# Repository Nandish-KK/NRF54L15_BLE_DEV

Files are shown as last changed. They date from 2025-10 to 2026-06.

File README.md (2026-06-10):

Project Banner

## Overview
This repository contains design files, libraries, and documentation for the NRF BLE transceiver project.
It is **not** an official NRF development board; it is a project I designed as an exercise while learning Altium Designer.

Project Render
(Renderd with [Blender](https://www.blender.org/) using [*pcb2blender*](https://github.com/30350n/pcb2blender) plugin for KiCAD)

## Things to play around with

- 6-axis IMU (BMI270)
- WS2812 Addressable RGB LED
- Coin cell operation
- Antenna switch for External antenna

## Folder Structure

```text
3D/				  # Contains STEP and Blender files
Altium/           # Altium project files and libraries
Datasheet/        # Datasheets and reference documents
Gerbers/          # Gerbers with PCB constraints optimized for JLCPCB
Pictures/         # Contains Render and Readme pictures
Reference/        # Additional reference layouts and guides
```

## Getting Started

1. Clone the repository:
	```bash
	git clone https://github.com/Nandish-KK/NRF54L15_BLE_DEV
	```
2. Open the Altium project file in `Altium/Nordic_BLE/Nordic_BLE.PrjPcb`.
3. Optionally you can import the Altium project in latest Kicad releases.

## Stackup

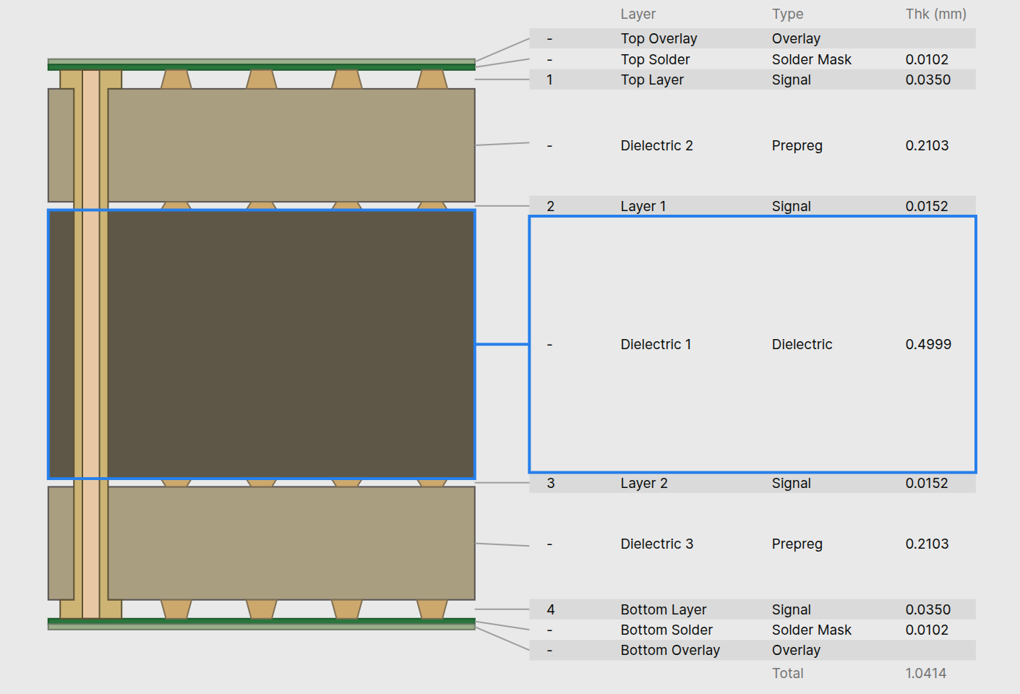
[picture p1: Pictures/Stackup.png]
Stackup


JLC04101H-7628

This is a 4-layer stackup with both of the Inner layers being solid ground planes.

## Project Preview

### Schematic
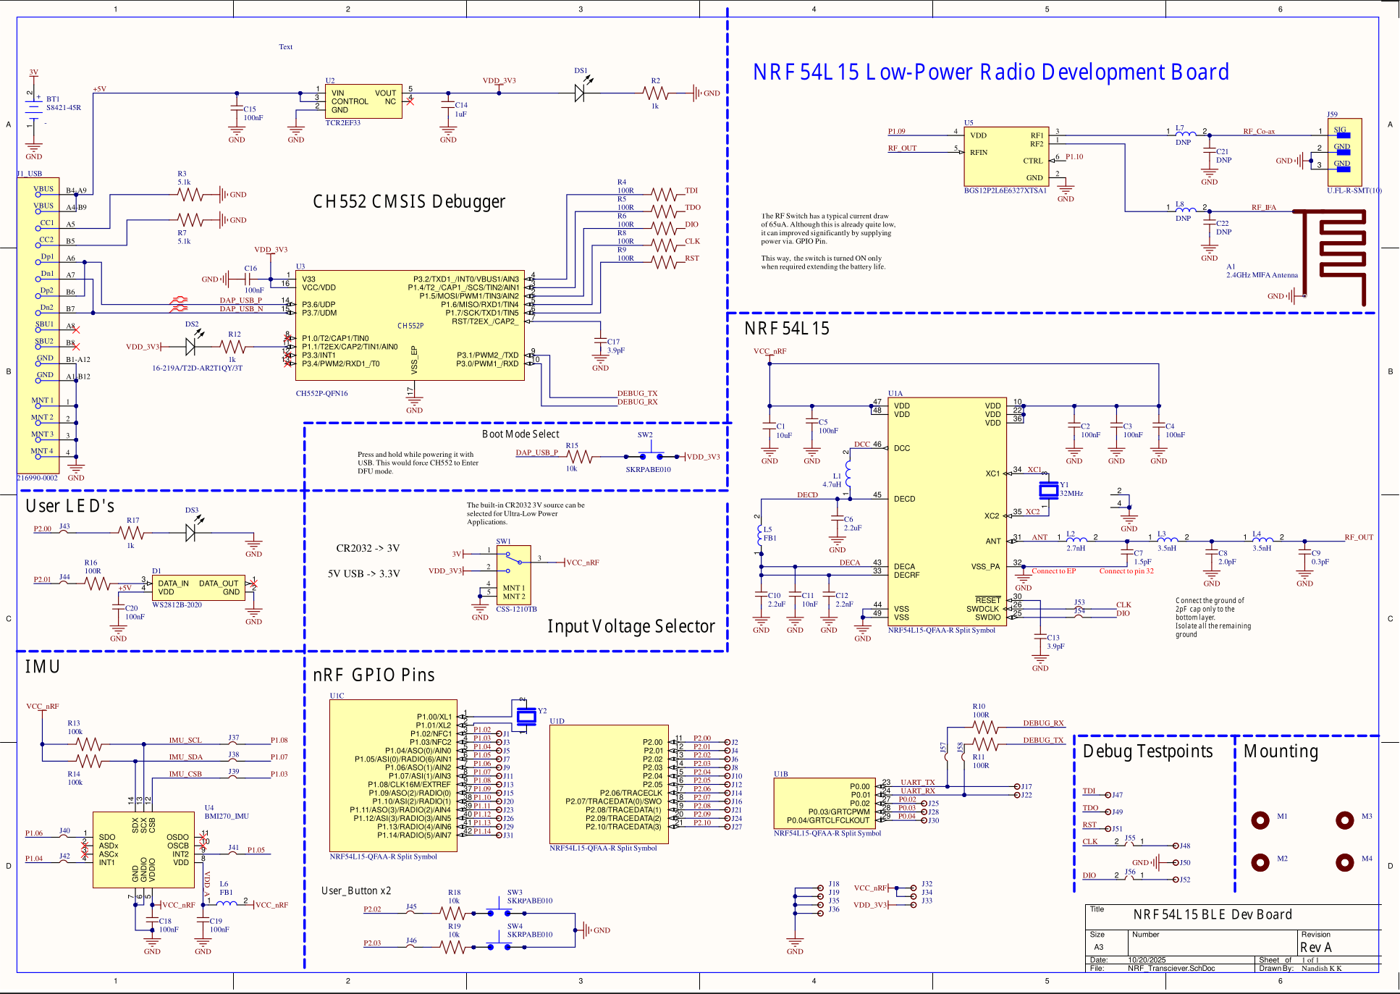
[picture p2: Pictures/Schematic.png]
Schematic Preview


### Top 3D View
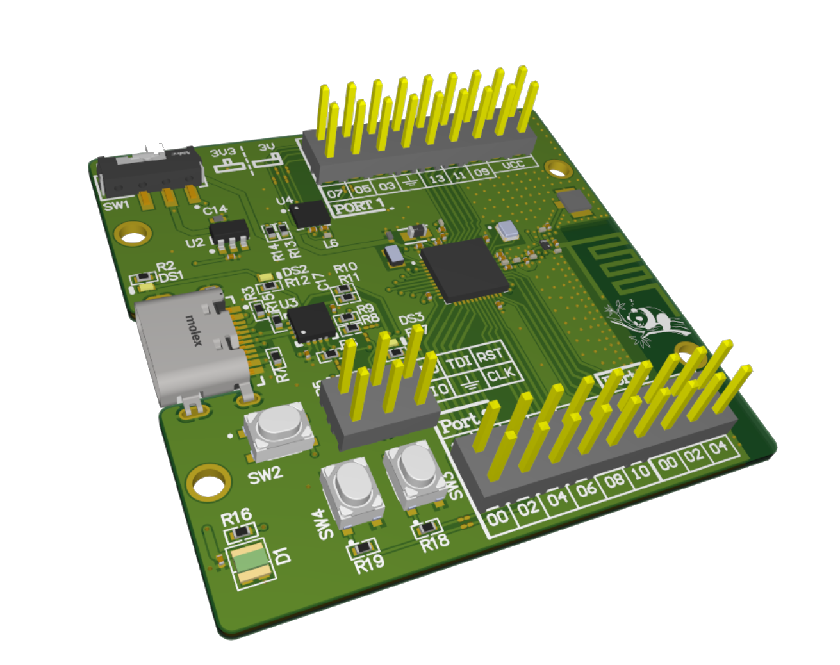
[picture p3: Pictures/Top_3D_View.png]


### Top Layer
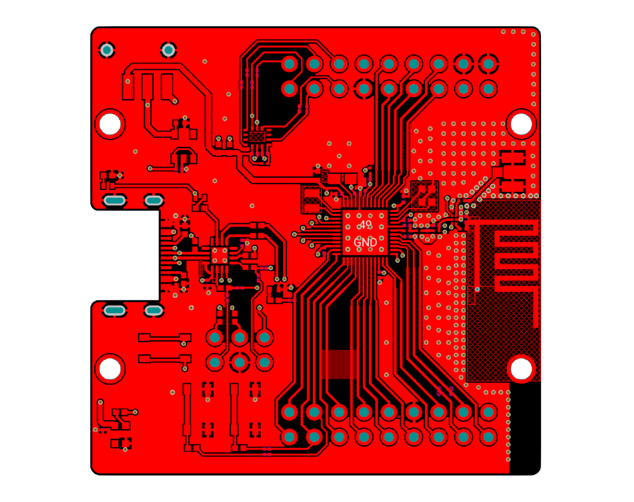
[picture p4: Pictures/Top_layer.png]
Layer_Top


### Bottom Layer
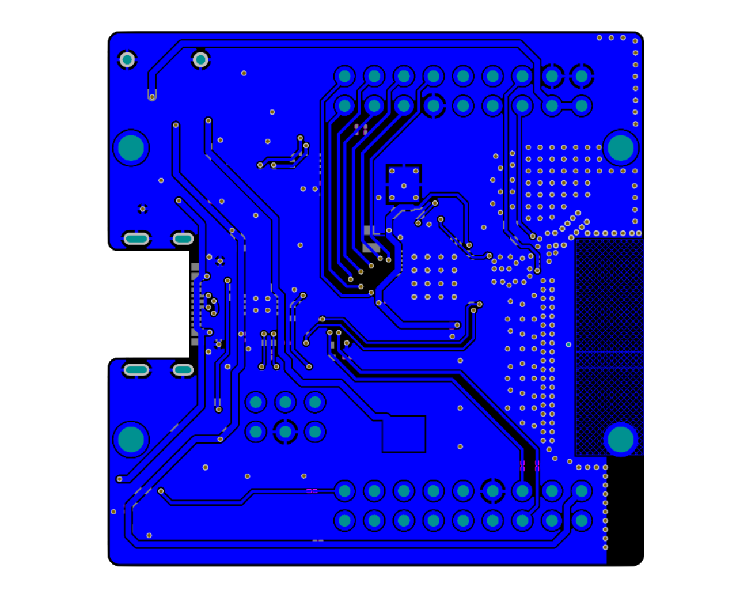
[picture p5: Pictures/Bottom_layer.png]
Layer_Bottom


### Bottom 3D View
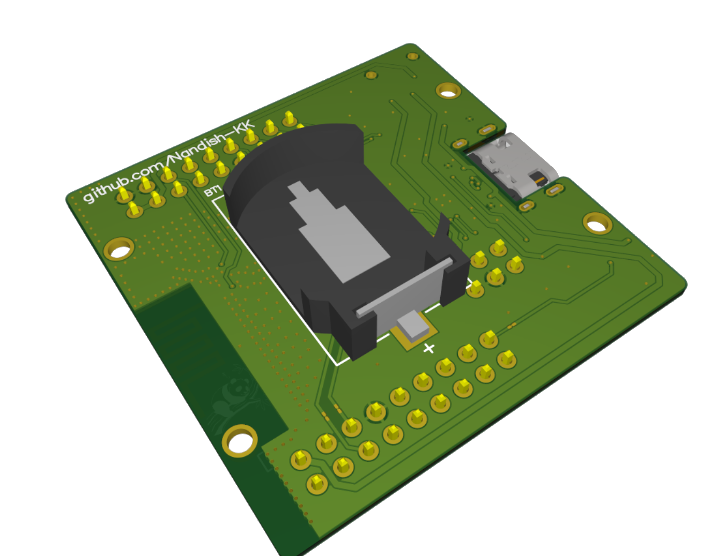
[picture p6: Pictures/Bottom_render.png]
Layer_Bottom


## Development bugs and fixes
The nrf54 controller comes with `AP_PROTECT` enabled by default. The debuggeres are unable to access the cpu and user flash memory for flashing. In order to unlock the `AP_PROTECT` and get access to the device, the nrf documentation recommends "mass erase". This process will clear the protection registers and allow for flashing.

If your using pyocd inside the nrf-connect terminal with west. During flash it will automatically detect the protection state and will try to erase before flashing. If that doesn't work, try external resets.
```bash
#from the project directory
$ west flash -d build_1/ -r pyocd

# --- OUTPUT ---
-- west flash: rebuilding
[0/5] Performing build step for 'hello_world'
ninja: no work to do.
[4/5] cd /home/user/path/to/project/dir/hello_world/build_1/_sysbuild && /home/user/ncs/toolchains/b2ecd2435d/usr/local/bin/cmake -E true
-- west flash: using runner pyocd
-- runners.pyocd: Flashing file: /media/renri/Hard_disk_Part1/NRF_playground/hello_world/build_1/merged.hex
0000496 W NRF54L15 APPROTECT enabled: will try to unlock via mass erase [target_nRF54L]
0001425 I Loading /home/user/path/to/project/dir/hello_world/build_1/merged.hex [load_cmd]
[==================================================] 100%
0005148 I Erased 36864 bytes (9 sectors), programmed 36864 bytes (9 pages), skipped 0 bytes (0 pages) at 9.75 kB/s [loader]
```

If the protection is enabled, the openenocd 'targets' command will report the main cpu status as unknown as shown below.

```
					 --- Locked State ---
> targets
    TargetName         Type       Endian TapName            State       
--  ------------------ ---------- ------ ------------------ ------------
 0* nrf54l.cpu         cortex_m   little nrf54l.cpu         unknown
 1  nrf54l.aux         mem_ap     little nrf54l.cpu         running

					--- Unlocked State ---
 > targets
    TargetName         Type       Endian TapName            State       
--  ------------------ ---------- ------ ------------------ ------------
 0* nrf54l.cpu         cortex_m   little nrf54l.cpu         running
 1  nrf54l.aux         mem_ap     little nrf54l.cpu         running
````

You can use the following pyocd commands to erase the chip. Although you can connect via openocd, there doesn't seem to be a relibale way to erase the chip with `AP_PROTECT` enabled.
Use the pyocd provided along with the nrf connect or install the latest version of pyocd if you prefere to use it externally. 

```bash
$ pyocd erase --mass --target nrf54l

# --- OUTPUT ---
0000395 W NRF54L15 is not in a secure state [target_nRF54L]
0000608 I Mass erasing device... [eraser]
0001324 I Mass erase complete [eraser]

```
If pyocd command fails to erase/flash with cmsis debugger, try power cycling.

[Working with the nRF52 Series' improved APPROTECT](https://devzone.nordicsemi.com/nordic/nordic-blog/b/blog/posts/working-with-the-nrf52-series-improved-approtect). 

Currently, I don't have J-link at hand. This meant I had to do quite a bit of detective work to come up with a solution. I found the solution in the seedstudio forum discussion on Xiao-nrf54l15. The discussion provides quite a bit of insight on the issues that you might face.
[Xiao-nrf54l15 Memory transfer fault](https://forum.seeedstudio.com/t/xiao-nrf54l15-an-error-occurred-memory-transfer-fault-0x00ffc31c-0x00ffc31f/293792/26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)
[Control access port protection documentation]

## Design Notes

* Hold the Boot button for uploading the CMSIS-DAP firmware for CH552 (first time only)
* Use the toggle switch to select the USB or Coin-cell operation
* The Antenna switch is powered with the GPIO _P1.09 and is controlled by GPIO P1.10; configure GPIOs for proper RF operation.
* Every GPIO used onboard has a bridger solder link. If any project requires these GPIOs externally, simply cut the closed solder bridge trace.

## On-Board Debugger

The Board design utilizes a CH552P microcontroller with a CMSIS-DAP firmware as a built-in debugger for NRF microcontroller. The CH552P is opted mainly due to its low cost and smaller footprint.
If you are designing your own board and would like to have a micro that is available at sites like digikey, mouser etc, then consider the SAMD11 series from microchip. These are fairly optimized for cost and size.

```
This project uses the Debugger implementation from wagiminator's CH552-DAPLink project.
Check out his project at: 

> github.com/wagiminator/CH552-DAPLink
> oshwlab.com/wagiminator/ch552g-daplink

```

## License
This work is licensed under CC BY-SA 4.0.
(https://creativecommons.org/licenses/by-sa/4.0/)

License


---

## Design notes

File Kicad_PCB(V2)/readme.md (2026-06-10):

#Rev 2 changes
- swapped RGB led gpio 
- Increased board dimension to account for better T-line design, testing and implement a pi matching network.

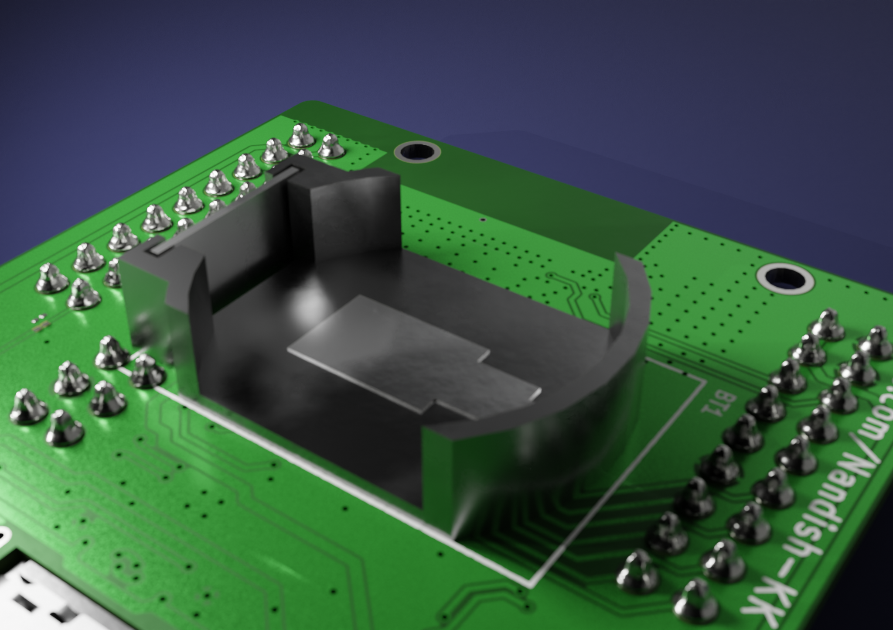
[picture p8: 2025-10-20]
Pictures/Coin_Cell_holder.png

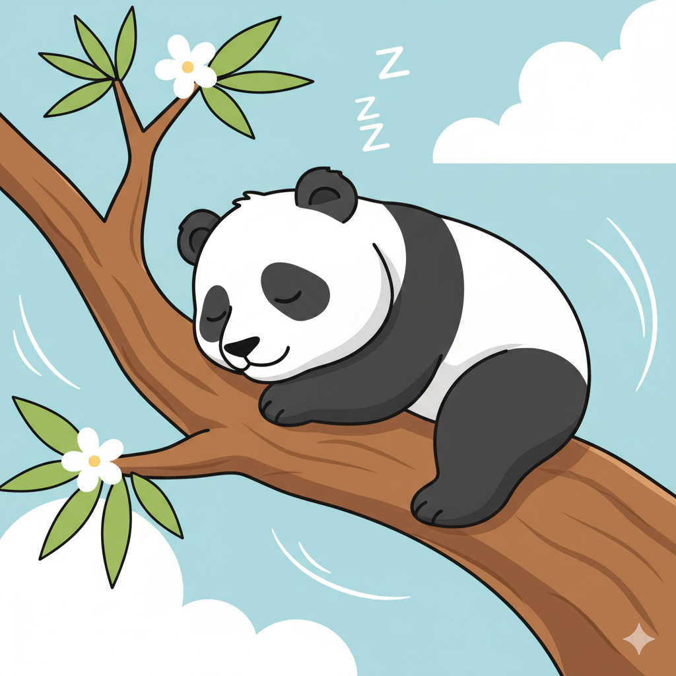
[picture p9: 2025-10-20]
Pictures/Gemini_Generated_Image_Prompt_create a vector like image of a cute panda sleeping on a branch.png

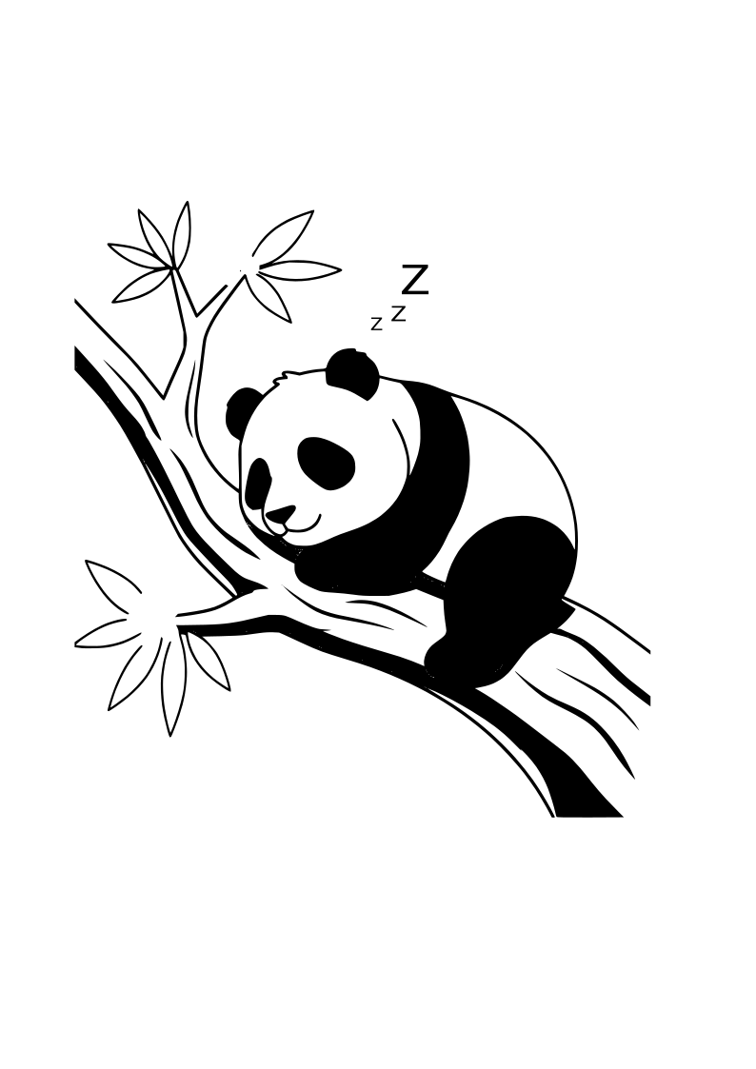
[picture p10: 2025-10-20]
Altium/Nordic_BLE/Sleeping_panda.png

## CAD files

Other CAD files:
3D/IMU_Demo.blend

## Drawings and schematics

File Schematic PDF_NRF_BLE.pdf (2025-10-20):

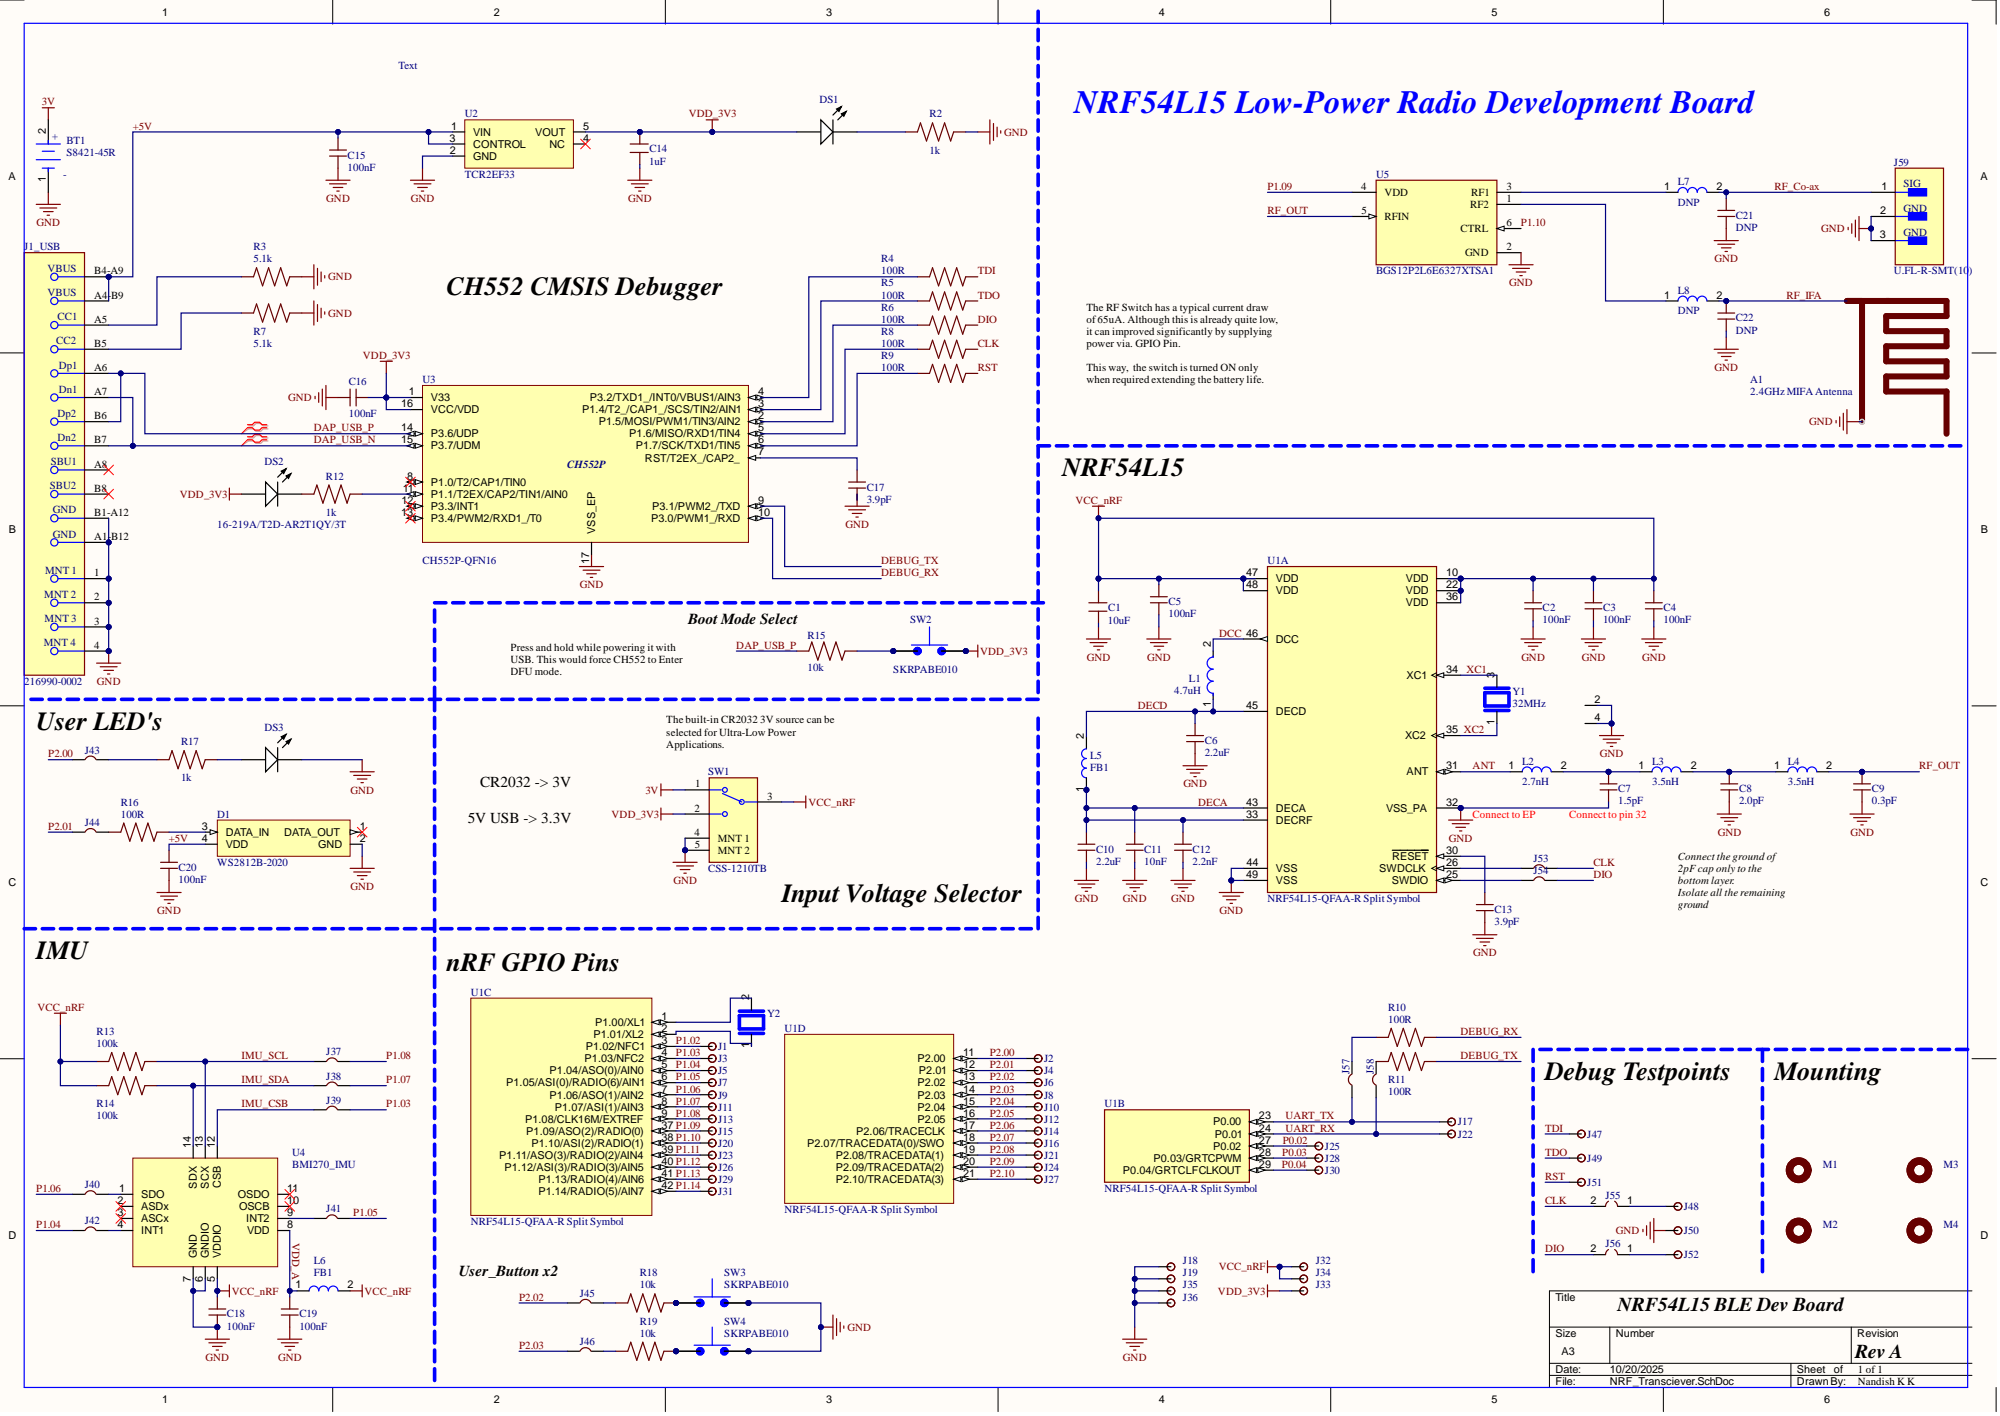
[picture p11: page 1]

NRF54L15 Low-Power Radio Development Board

The RF Switch has a typical current draw
of 65uA. Although this is already quite low,
it can improved significantly by supplying
power via. GPIO Pin.

This way, the switch is turned ON only
when required extending the battery life.

Press and hold while powering it with
USB. This would force CH552 to Enter
DFU mode.

The built-in CR2032 3V source can be
selected for Ultra-Low Power
Applications.

Connect the ground of
2pF cap only to the
bottom layer.
Isolate all the remaining
ground

Size A3 | Number | Revision

Date: 10/20/2025 | Sheet of
File: NRF_Transciever.SchDoc | Drawn By: Nandish K K

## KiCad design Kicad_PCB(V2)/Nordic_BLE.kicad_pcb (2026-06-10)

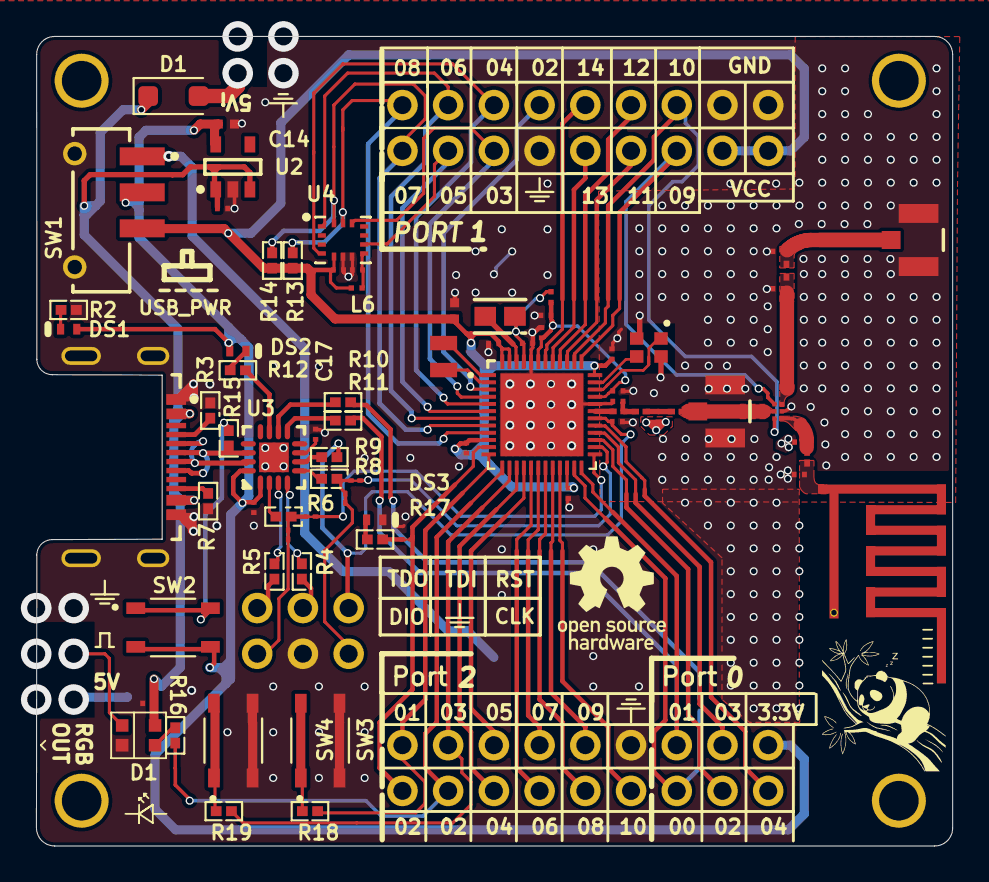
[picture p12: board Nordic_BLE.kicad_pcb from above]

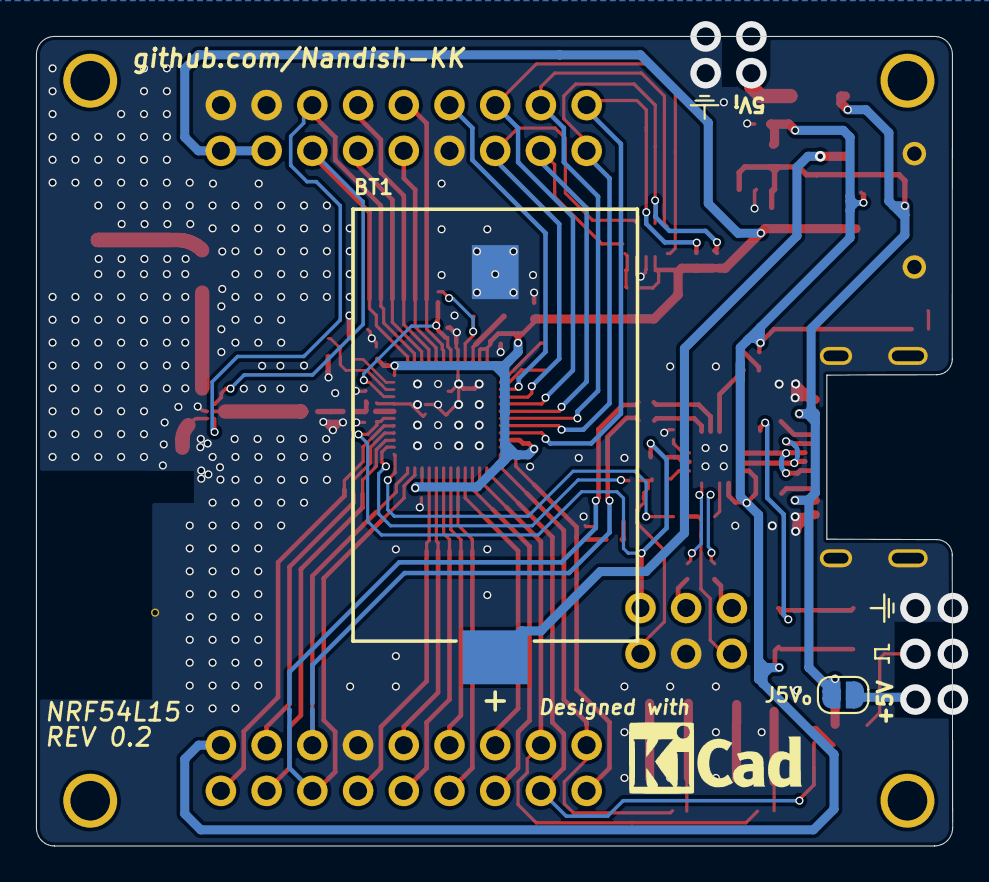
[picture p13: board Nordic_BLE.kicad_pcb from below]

Board: 4 copper layers, 50.9 x 45.0 mm, 124 parts (4 on the bottom side), 82 nets.

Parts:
A1: 2.4GHz MIFA Antenna; 2.4GHZ MIFA
BT1: S8421-45R; FP-S8421-45R-MFG
C1: 10uF; 0402_SMD_CAPACITOR
C2, C3, C4, C5, C15, C16, C18, C19, C20: 100nF; 0201 SMD CAPACITOR
C6, C10: 2.2uF; 0201 SMD CAPACITOR
C7: 1.5pF; 0201 SMD CAPACITOR
C8: 2.0pF; 0201 SMD CAPACITOR
C11: 10nF; 0201 SMD CAPACITOR
C12: 2.2nF; 0201 SMD CAPACITOR
C13, C17: 3.9pF; 0201 SMD CAPACITOR
C14: 1uF; 0402_SMD_CAPACITOR
C21, C21#2, C22, C22#2: DNP; 0201 SMD Capacitor
D1: D_SOD-123F
D1#2: WS2812B-2020
DS1, DS2, DS3: 16-219A/T2D-AR2T1QY/3T; EVRL-0402-2_V
J1, J2, J3, J4, J5, J6, J7, J8, J9, J10, J11, J12, J13, J14, J15, J16, J17, J18, J19, J20, J21, J22, J23, J24, J25, J26, J27, J28, J29, J30, J31, J32, J33, J34, J35, J36, J47, J48, J49, J50, J51, J52: Single_Header_2.54mm; SINGLE_HEADER_2.54MM
J1_USB: 216990-0002; FP-216990-0002-MFG
J5V_{o}: SolderJumper-2_P1.3mm_Open_RoundedPad1.0x1.5mm
J43, J53, J54, J57, J58: Shorted_Solder_Bridge; SHORTED_SOLDER_BRIDGE
J55, J56: Open_Solder_Bridge; OPEN_SOLDER_BRIDGE
J59, J59#2: U.FL-R-SMT(10); FP-U_FL-R-SMT_10-MFG
L1: 4.7uH; FP-MLZ1608-IPC_A
L2: 2.7nH; 0201_SMD_INDUCTOR
L3, L4: 3.5nH; 0201_SMD_INDUCTOR
L5, L6: FB1; 0201_SMD_INDUCTOR
L7, L8: DNP; 0201_SMD_INDUCTOR
M1, M2, M3, M4: M2_Mounting_Hole; M2 MOUNTING HOLE
R2, R12, R17: 1k; RES_0402_GENERIC
R3, R7: 5.1k; RES_0402_GENERIC
R4, R5, R6, R8, R9, R10, R11, R16: 100R; RES_0402_GENERIC
R13, R14: 100k; RES_0402_GENERIC
R15, R18, R19: 10k; RES_0402_GENERIC
SW1: CSS-1210TB; FP-CSS-1210TB-MFG
SW2, SW3, SW4: SKRPABE010; SW_SKRPABE010
U1: NRF54L15-QFAA-R Split Symbol; NRF54L15_LQFN_48
U2: TCR2EF33; TCR2EF33-SOT-23-5
U3: CH552P-QFN16; CH552-QFN16_3X3
U4: BMI270_IMU; BMI_270_PQFN50P300X250X70-14L
U5: BGS12P2L6E6327XTSA1; FP-PG-TSLP-6-MFG
Y1: 32MHz; OSC_XRCGB32M000F2P01R0
Y2: CM8V-T1A-32.768KHZ-9PF-20PPM-TA-QC; XTAL_CM8V-T1A-32.768KHZ-9PF-20PPM-TA-QC

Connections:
3V: BT1.2, SW1.1
+5V: C15.2, C20.2, D1.1, D1#2.4, J1_USB.A4-B9, J1_USB.B4-A9, J5V_{o}.2, U2.1, U2.3
ANT: L2.1, U1.31
CLK: J53.2, J55.2, R8.2
DAP_USB_N: J1_USB.A7, J1_USB.B7, U3.15
DAP_USB_P: J1_USB.A6, J1_USB.B6, R15.1, U3.14
DCC: L1.2, U1.46
DEBUG_RX: R10.1, U3.10
DEBUG_TX: R11.2, U3.9
DECA: C10.2, C11.2, C12.2, L5.1, U1.33, U1.43
DECD: C6.2, L1.1, L5.2, U1.45
DIO: J54.2, J56.2, R6.2
GND: A1.2, BT1.1, C1.1, C2.1, C3.1, C4.1, C5.1, C6.1, C7.1, C8.1, C10.1, C11.1, C12.1, C13.1, C14.1, C15.1, C16.1, C17.1, C18.1, C19.1, C20.1, C21.1, C21#2.1, C22.1, C22#2.1, D1#2.2, DS3.2, J1_USB.1, J1_USB.2, J1_USB.3, J1_USB.4, J1_USB.A1-B12, J1_USB.B1-A12, J18.1, J19.1, J35.1, J36.1, J50.1, J59.2, J59.3, J59#2.2, J59#2.3, R2.1, R3.1, R7.1, SW1.4, SW1.5, SW3.3, SW3.4, SW4.3, SW4.4, U1.32, U1.44, U1.49, U2.2, U3.17, U4.6, U4.7, U5.2, Y1.2, Y1.4
NetC7_2: C7.2, L2.2, L3.1
NetC8_2: C8.2, L3.2, L4.1
NetC17_2: C17.2, U3.7
NetD1_3: D1#2.3, R16.2
NetDS1_2: DS1.2, R2.2
NetDS2_2: DS2.2, R12.2
NetDS3_1: DS3.1, R17.1
NetJ1_USB_A5: J1_USB.A5, R3.2
NetJ1_USB_B5: J1_USB.B5, R7.2
NetJ43_2: J43.2, R17.2
NetJ48_1: J48.1, J55.1
NetJ52_1: J52.1, J56.1
NetJ53_1: J53.1, U1.26
NetJ54_1: J54.1, U1.25
NetJ57_2: J57.2, R10.2
NetJ58_2: J58.2, R11.1
NetL7_1: C21.2, L7.1, U5.3
NetL8_1: C22.2, L8.1, U5.1
NetR4_1: R4.1, U3.4
NetR5_1: R5.1, U3.3
NetR6_1: R6.1, U3.2
NetR8_1: R8.1, U3.5
NetR9_1: R9.1, U3.6
NetR12_1: R12.1, U3.11
NetR15_2: R15.2, SW2.1, SW2.2
NetR18_1: R18.1, SW3.1, SW3.2
NetR19_1: R19.1, SW4.1, SW4.2
NetU1_1: U1.1, Y2.2
NetU1_2: U1.2, Y2.1
P0.02: J25.1, U1.27
P0.03: J28.1, U1.28
P0.04: J30.1, U1.29
P1.02: J1.1, U1.3
P1.03: J3.1, U1.4, U4.12
P1.04: J5.1, U1.5, U4.4
P1.05: J7.1, U1.6, U4.9
P1.06: J9.1, U1.7, U4.1
P1.07: J11.1, R14.1, U1.8, U4.14
P1.08: J13.1, R13.1, U1.9, U4.13
P1.09: J15.1, U1.37, U5.4
P1.10: J20.1, U1.38, U5.6
P1.11: J23.1, U1.39
P1.12: J26.1, U1.40
P1.13: J29.1, U1.41
P1.14: J31.1, U1.42
P2.00: J2.1, J43.1, U1.11
P2.01: J4.1, R18.2, U1.12
P2.02: J6.1, R16.1, U1.13
P2.03: J8.1, R19.2, U1.14
P2.04: J10.1, U1.15
P2.05: J12.1, U1.16
P2.06: J14.1, U1.17
P2.07: J16.1, U1.18
P2.08: J21.1, U1.19
P2.09: J24.1, U1.20
P2.10: J27.1, U1.21
RF_Co-ax: C21#2.2, J59.1, L7.2
RF_IFA: A1.1, C22#2.2, L8.2
RF_OUT: J59#2.1, L4.2, U5.5
RST: C13.2, J51.1, R9.2, U1.30
TDI: J47.1, R4.2
TDO: J49.1, R5.2
UART_RX: J22.1, J58.1, U1.24
UART_TX: J17.1, J57.1, U1.23
VCC_nRF: C1.2, C2.2, C3.2, C4.2, C5.2, C18.2, J32.1, J34.1, L6.2, R13.2, R14.2, SW1.3, U1.10, U1.22, U1.36, U1.47, U1.48, U4.5
VDD_3V3: C14.2, C16.2, DS1.1, DS2.1, J33.1, SW1.2, SW2.3, SW2.4, U2.5, U3.1, U3.16
VDD_A: C19.2, L6.1, U4.8
XC1: U1.34, Y1.1
XC2: U1.35, Y1.3

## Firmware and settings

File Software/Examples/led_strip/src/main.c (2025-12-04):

/*
 * Copyright (c) 2017 Linaro Limited
 * Copyright (c) 2018 Intel Corporation
 * Copyright (c) 2024 TOKITA Hiroshi
 *
 * SPDX-License-Identifier: Apache-2.0
 */

#include <errno.h>
#include <string.h>

#define LOG_LEVEL 4
#include <zephyr/logging/log.h>
LOG_MODULE_REGISTER(main);

#include <zephyr/kernel.h>
#include <zephyr/drivers/led_strip.h>
#include <zephyr/device.h>
#include <zephyr/drivers/spi.h>
#include <zephyr/sys/util.h>

#define STRIP_NODE		DT_ALIAS(led_strip)

#if DT_NODE_HAS_PROP(DT_ALIAS(led_strip), chain_length)
#define STRIP_NUM_PIXELS	DT_PROP(DT_ALIAS(led_strip), chain_length)
#else
#error Unable to determine length of LED strip
#endif

#define DELAY_TIME K_MSEC(CONFIG_SAMPLE_LED_UPDATE_DELAY)

#define RGB(_r, _g, _b) { .r = (_r), .g = (_g), .b = (_b) }

static const struct led_rgb colors[] = {
	RGB(CONFIG_SAMPLE_LED_BRIGHTNESS, 0x00, 0x00), /* red */
	RGB(0x00, CONFIG_SAMPLE_LED_BRIGHTNESS, 0x00), /* green */
	RGB(0x00, 0x00, CONFIG_SAMPLE_LED_BRIGHTNESS), /* blue */
};

static struct led_rgb pixels[STRIP_NUM_PIXELS];

static const struct device *const strip = DEVICE_DT_GET(STRIP_NODE);

int main(void)
{
	 k_sleep(K_MSEC(1000)); 
	size_t color = 0;
	int rc;

	if (device_is_ready(strip)) {
		LOG_INF("Found LED strip device %s", strip->name);
	} else {
		LOG_ERR("LED strip device %s is not ready", strip->name);
		return 0;
	}
	printf("Running\n");

	LOG_INF("Displaying pattern on strip");
	while (1) {
		for (size_t cursor = 0; cursor < ARRAY_SIZE(pixels); cursor++) {
			memset(&pixels, 0x00, sizeof(pixels));
			memcpy(&pixels[cursor], &colors[color], sizeof(struct led_rgb));

			rc = led_strip_update_rgb(strip, pixels, STRIP_NUM_PIXELS);
			if (rc) {
				LOG_ERR("couldn't update strip: %d", rc);
			}

			k_sleep(DELAY_TIME);
		}

		color = (color + 1) % ARRAY_SIZE(colors);
	}

	return 0;
}

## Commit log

2026-06-10 Added V2 Kicad PCB and removed VNA results folder
    [IMU_Demo.blend, NRF.blend]
2026-06-10 updated readme, examples and added V2
    [Nordic_BLE-Bottom Layer.gbr, Nordic_BLE-Bottom Overlay.gbr, Nordic_BLE-Bottom Paste.gbr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]
